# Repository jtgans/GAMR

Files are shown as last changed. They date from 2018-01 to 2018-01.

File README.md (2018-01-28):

GAMR Logo

This is an electronics hacking project that involves building
a [TerasIC DE0-Nano FPGA board][TerasIC] into a simplistic, fun, and
retargetable handheld gaming console.

[TerasIC]: http://www.terasic.com.tw/cgi-bin/page/archive.pl?Language=English&CategoryNo=139&No=593&PartNo=1

## Design

The console consists of three major parts:

  - The Left and Right controller (both using the same components and basic
    schematic -- only the board art is different)
  - The TFT LCD backlight, power, and audio amp board
  - Adapters for the speakers

This repository contains the Eagle 8.x projects, the Altera Cyclone IV VHDL
source code for the cores, as well as a few bits of software written for the
console.

## Spirit of the Project

The idea is to make this as drop-dead simple to build as possible, minus the
fabbing of the boards. As a result, it'll use mostly through-hole components,
0608-class SMT parts if absolutely necessary, and 0.1" headers wherever
interconnects are required. Everything should be hand-assembleable by someone
with minimal electronics experience without expensive rework stations.

Component counts should be kept as minimal as possible. Anything that could
typically be done using a piece of discrete hardware (say, a SID chip, or a
fancy DAC, video controller, CPU, etc.) should ideally be done in the FPGA to
keep things as simple and malleable as possible.

The boards included in this repository will likely be built using OSHpark
or some other OSS-friendly project, so just look for the "GAMR" acronym in their
catalogs.

As of this writing, the following boards are now in production:

  * [Left Controller][left-controller]
  * [Right Controller][right-controller]

[left-controller]: https://oshpark.com/shared_projects/AXFgIkdE
[right-controller]: https://oshpark.com/shared_projects/QkbYnFhj

## Why "GAMR"? What's it mean?

I dunno. PiGrrl, GameGrrl, FPGamer... GAMR. Doesn't really mean anything -- I
needed a name, so I chose that. =o)

## License

This project is placed under the WTFPL. You can do what the f--- you'd like with
it. Depending on whether or not more people get involved, I may change this to
something more sane if folks would like to collaborate more. One thing to note:
I'm not planning on making money on it, but maybe you can on Tindie. =o)

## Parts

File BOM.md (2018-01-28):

# Bill of Materials

Most of these parts come straight from Adafruit industries. I've tried to
provide links here to the appropriate product pages, but can't guarantee they'll
stay available. Worse, I'm not sure what Digikey or Mouser part numbers they
use, so sourcing equivalents may be a bit of a chore -- especially when it comes
to mechanicals.

I've listed the Adafruit device names in parens where I can.

## Main Body

Obviously you're going to need a DE0-Nano, though any Cyclone IV or V-based dev
board from TerasIC will work. I bought [this one][DE0-Nano] from Adafruit, which
corresponds to [this product page][TerasIC].

Other components you'll need:

  * 1 x [5" 40-pin 800x480 TFT Display without touchscreen (the bare one!)][body1]
  
[DE0-Nano]: https://www.adafruit.com/product/451
[TerasIC]: http://www.terasic.com.tw/cgi-bin/page/archive.pl?Language=English&CategoryNo=139&No=593&PartNo=1
[body1]: https://www.adafruit.com/product/1680

## TFT Driver, Power, and Audio Amp Board

Note: the TFT driver components and circuit design is based upon Adafruit's
[40-pin TFT friend][tft-friend]. The audio amplifier is of my own design.

*Digikey BOM TBD*
  * *Want a headphone jack? Not really, ugh, but could be useful...*
  * *Simple LiPoly Battery Circuit and power distribution?*
  * *Bog-simple i2c/SPI uC wifi for uploading of sketches? Expansion later?*
  * 2 x [Thin Plastic Speaker w/ Wires - 8ohm 0.25W][audio1]

[tft-friend]: https://github.com/adafruit/Adafruit-40-pin-TFT-Friend
[audio1]: https://www.adafruit.com/product/1891

## Controllers (Left and Right are identical)

Quantities listed are *per controller*.

  * 5 x [Omron 12mm Tactile Switches (B3F-40xx)][cont1]
  * 1 x [Analog 2-axis Thumb Joystick with Select Button (JOYSTICK)][cont2]
  * 1 x [1x10 0.1" right angle male headers][cont3]

[cont1]: https://www.adafruit.com/product/1009
[cont2]: https://www.adafruit.com/product/512
[cont3]: https://www.adafruit.com/product/1540

### Assembly Notes

  * The 0.1" headers should be soldered on the *back* of the board, fingering the
    underside.
  * Use some form of ribbon cable or jumper cable with 0.1"-style connectors on
    each end. Ideally in something like a 2x6 terminal block one end to make it
    easier to plug into the DE0-Nano. Using [jumper cables like these][jumpers]
    will work, too. Ideally, get some
    of [these single row housings][by-one-jumper-housings],
    or [these dual row housings][by-two-jumper-housings], along with some wire
    and [raw jumper cables][raw-jumper-cables] to make custom jumper blocks.
    
[jumpers]: https://www.adafruit.com/product/1950
[by-one-jumper-housings]: https://www.adafruit.com/product/3146
[by-two-jumper-housings]: https://www.adafruit.com/product/3144
[raw-jumper-cables]: https://www.adafruit.com/product/3141

### Circuit Notes

The buttons are designed to short to `GND` when pressed, including the switch
built into the analog joystick. To make this work properly, however, you need to
configure the GPIOs in the FPGA to turn on their pull up resistors.

The `JOY_V` and `JOY_H` lines are analog and will require connections to the ADC
built into the DE0-Nano.

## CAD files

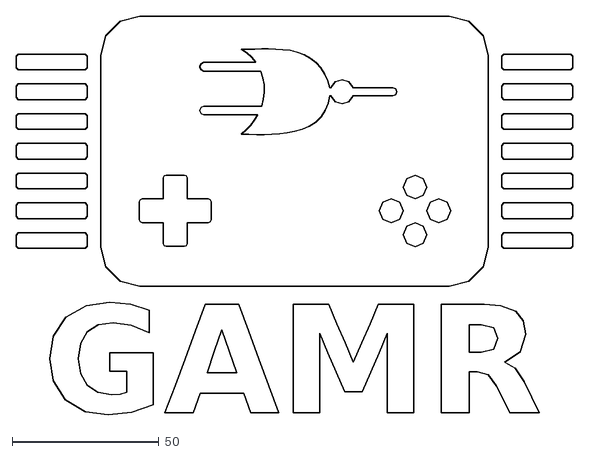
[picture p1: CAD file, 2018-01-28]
logos/gamr-eagle.dxf
189.9 x 136.0

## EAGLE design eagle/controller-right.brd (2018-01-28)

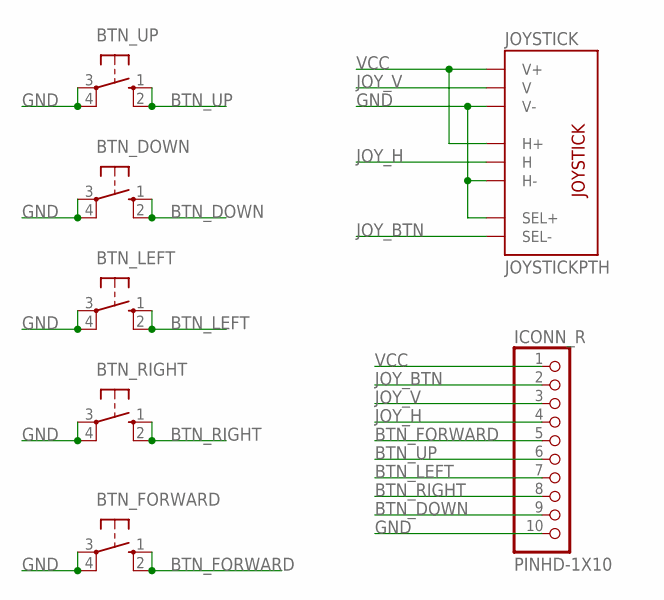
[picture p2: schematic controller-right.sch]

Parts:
BTN_DOWN: 40-XX-ROUND; B3F-40XX-ROUND
BTN_FORWARD: 40-XX-ROUND; B3F-40XX-ROUND
BTN_LEFT: 40-XX-ROUND; B3F-40XX-ROUND
BTN_RIGHT: 40-XX-ROUND; B3F-40XX-ROUND
BTN_UP: 40-XX-ROUND; B3F-40XX-ROUND
ICONN_R: PINHD-1X10; 1X10-BIG
JOYSTICK: JOYSTICKPTH; JOYSTICK

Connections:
BTN_DOWN: BTN_DOWN.1 (S), BTN_DOWN.2 (S1), ICONN_R.9
BTN_FORWARD: BTN_FORWARD.1 (S), BTN_FORWARD.2 (S1), ICONN_R.5
BTN_LEFT: BTN_LEFT.1 (S), BTN_LEFT.2 (S1), ICONN_R.7
BTN_RIGHT: BTN_RIGHT.1 (S), BTN_RIGHT.2 (S1), ICONN_R.8
BTN_UP: BTN_UP.1 (S), BTN_UP.2 (S1), ICONN_R.6
GND: BTN_DOWN.3, BTN_DOWN.4 (P1), BTN_FORWARD.3, BTN_FORWARD.4 (P1), BTN_LEFT.3, BTN_LEFT.4 (P1), BTN_RIGHT.3, BTN_RIGHT.4 (P1), BTN_UP.3, BTN_UP.4 (P1), ICONN_R.10, JOYSTICK.B1A (SEL+), JOYSTICK.H3 (H-), JOYSTICK.V3 (V-)
JOY_BTN: ICONN_R.2, JOYSTICK.B2A (SEL-)
JOY_H: ICONN_R.4, JOYSTICK.H2 (H)
JOY_V: ICONN_R.3, JOYSTICK.V2 (V)
VCC: ICONN_R.1, JOYSTICK.H1 (H+), JOYSTICK.V1 (V+)

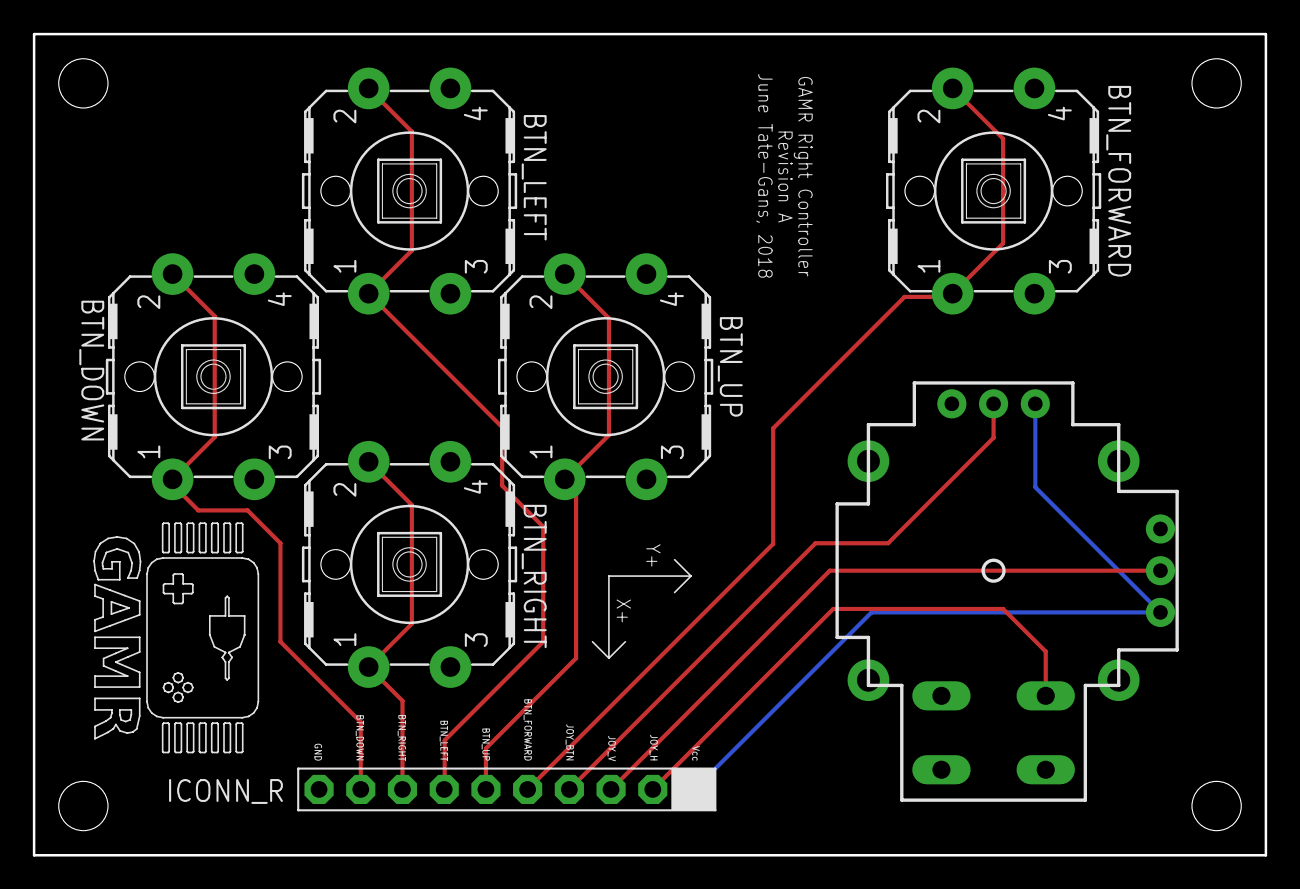
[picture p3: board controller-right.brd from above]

Board: 2 copper layers, 75.0 x 50.0 mm, 7 parts (0 on the bottom side), 10 nets.

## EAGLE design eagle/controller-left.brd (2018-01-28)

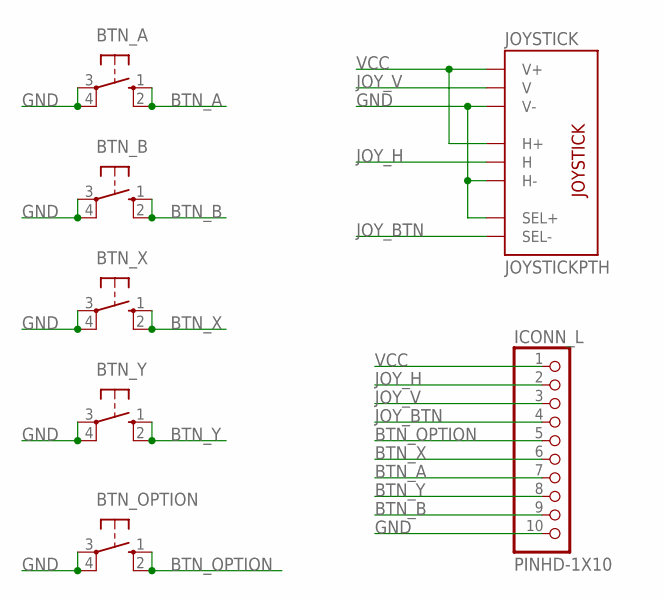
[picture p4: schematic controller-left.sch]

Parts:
BTN_A: 40-XX-ROUND; B3F-40XX-ROUND
BTN_B: 40-XX-ROUND; B3F-40XX-ROUND
BTN_OPTION: 40-XX-ROUND; B3F-40XX-ROUND
BTN_X: 40-XX-ROUND; B3F-40XX-ROUND
BTN_Y: 40-XX-ROUND; B3F-40XX-ROUND
ICONN_L: PINHD-1X10; 1X10-BIG
JOYSTICK: JOYSTICKPTH; JOYSTICK

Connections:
BTN_A: BTN_A.1 (S), BTN_A.2 (S1), ICONN_L.7
BTN_B: BTN_B.1 (S), BTN_B.2 (S1), ICONN_L.9
BTN_OPTION: BTN_OPTION.1 (S), BTN_OPTION.2 (S1), ICONN_L.5
BTN_X: BTN_X.1 (S), BTN_X.2 (S1), ICONN_L.6
BTN_Y: BTN_Y.1 (S), BTN_Y.2 (S1), ICONN_L.8
GND: BTN_A.3, BTN_A.4 (P1), BTN_B.3, BTN_B.4 (P1), BTN_OPTION.3, BTN_OPTION.4 (P1), BTN_X.3, BTN_X.4 (P1), BTN_Y.3, BTN_Y.4 (P1), ICONN_L.10, JOYSTICK.B1A (SEL+), JOYSTICK.H3 (H-), JOYSTICK.V3 (V-)
JOY_BTN: ICONN_L.4, JOYSTICK.B2A (SEL-)
JOY_H: ICONN_L.2, JOYSTICK.H2 (H)
JOY_V: ICONN_L.3, JOYSTICK.V2 (V)
VCC: ICONN_L.1, JOYSTICK.H1 (H+), JOYSTICK.V1 (V+)

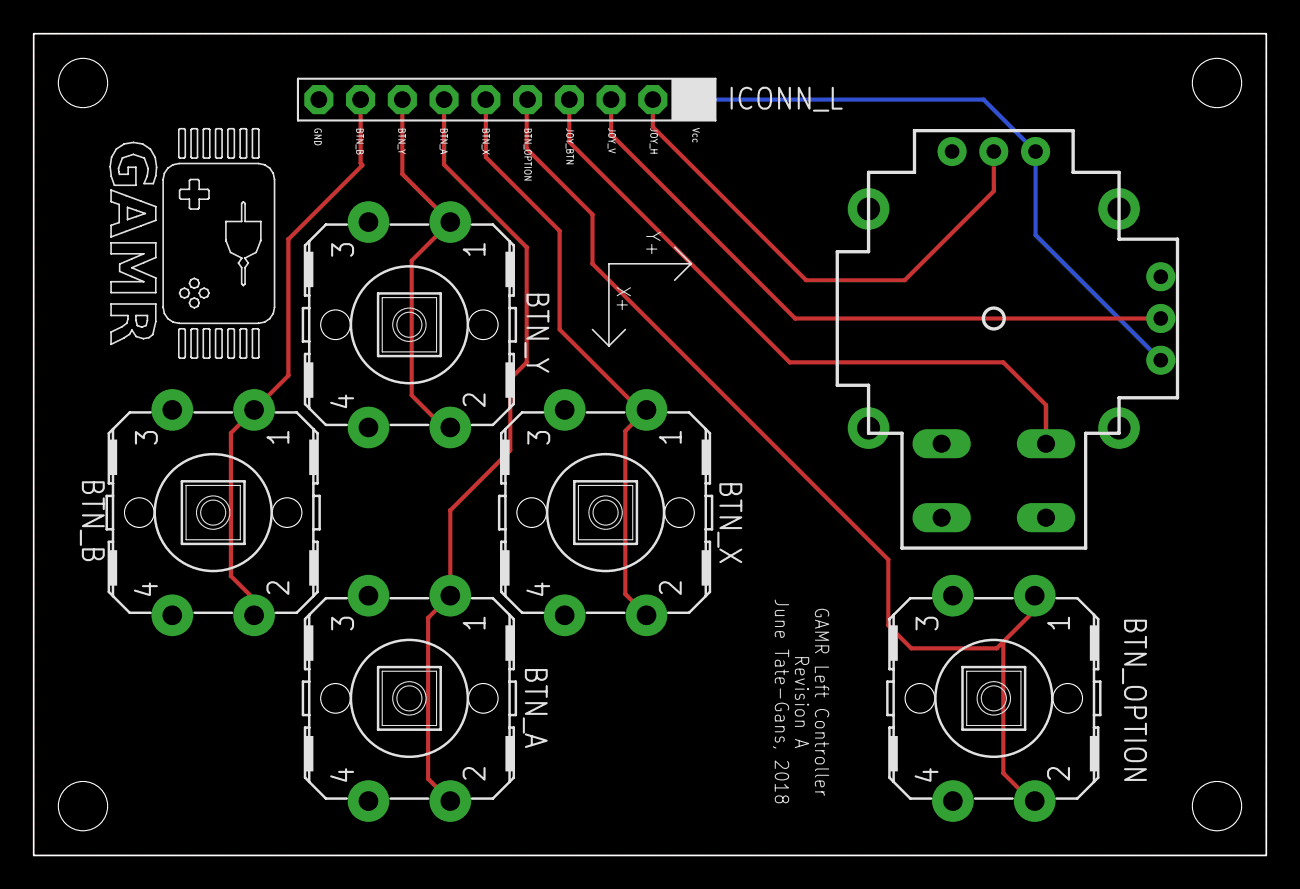
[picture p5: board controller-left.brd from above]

Board: 2 copper layers, 75.0 x 50.0 mm, 7 parts (0 on the bottom side), 10 nets.

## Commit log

2018-01-28 controllers: Adding the left controller and logos
    Draws out the first version of the left controller board, the Eagle
    project file, and also a bunch of logos that I'll be using in the
    project.
    [controller-left.brd, controller-left.sch, gamr-flat-white.dxf]
2018-01-28 cleanups: Moving stuff around fixing logos, etc.
    This moves the eagle project into its own directory, fixes up the logos
    a bit, and fixes the README.md file a bit more to match up with the new
    heirarchy.
    [controller-left.brd, controller-left.sch, gamr-eagle.dxf]
2018-01-28 left-controller: Fix some silkscreen issues.
    [controller-left.brd, controller-left.sch]
2018-01-28 left-controller: Routing adjustments
    The previews for the routing of lines inside the omron tactile switches
    was a bit too tight for the copper pour. Moved them away from some of
    the pads to compensate.
    Also minor silkscreen touches to indicate pin 1 on the ICONN_L header.
    Should prevent misorientation of the interconnects.
    [controller-left.brd]
2018-01-28 controller: Adding in the rev. A right controller
    This adds in the right controller to the tree.
    [controller-right.brd, controller-right.sch]
2018-01-28 bom: Adding in a bill of materials
2018-01-28 bom: Adding in more parts I missed
    Adding in additional info about the components and where to get them.
2018-01-28 bom: More info on jumper cables
    General info on how to make cables that don't suck.
2018-01-28 logo: Fix the notted AND-gate
    Seriously. A notted AND is /not/ a NAND. This ditches it in favor of a
    NOR gate, which is just as good. I wanted something like that to
    symbolize the NOR logic embedded in FPGAs.
    [gamr-eagle.dxf]
